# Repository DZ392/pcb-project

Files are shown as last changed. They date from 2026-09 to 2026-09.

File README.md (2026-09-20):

# pcb-project

🦋 Butterfly USB Hub Dongle

This is a small 4-port USB hub built into a butterfly-shaped PCB. Instead of using a cable like most USB hubs, it plugs directly into the side of a laptop.

I wanted to make something a more compact usb that can be used for anything I need, so I designed mine as a dongle and I wanted it to work with newer laptops that mostly use USB-C as well as older ones that still have USB-A.

The board has a male USB-C connector and a male USB-A connector for the laptop side. You only use one of them at a time depending on what port your laptop has.

I also wanted the PCB itself to be part of the design rather than just a rectangular board, so I shaped it like a butterfly and plan to add a UV-printed gradient design to it as a challenge. 

The PCB is 1.2 mm thick to work with the edge-mount USB connectors.

Why I Made It

I use devices with both USB-A and USB-C, and I thought it would be useful to have one small hub that could plug into either type of laptop without needing another adapter or cable. I also wanted to try designing my first PCB for practice. 

I started by following the Macondo USB hub tutorial to understand how a USB hub circuit works. From there, I changed the design, I added both USB-C and USB-A upstream connectors, changed it into a direct-plug dongle, designed the butterfly-shaped PCB, and added my own visual design.

This project has also helped to learn KiCad and understand how the schematic, PCB layout, footprints, connectors, and physical board shape all have to work together.

How to Use It

1. Plug either the USB-C or USB-A connector into your laptop. Only one should be connected at a time.
2. Plug USB-A devices into the three USB-A ports on the board.
3. A USB-C device can also be connected to the USB-C port on the hub.

* Hub IC: CoreChips SL2.1S
* USB standard: USB 2.0
* Upstream: 1 × male USB-C + 1 × male USB-A
* Downstream: 3 × female USB-A + 1 × female USB-C
* PCB: 2-layer, 1.2 mm thick
* Size: about 75 mm × 65 mm
* Board shape: custom butterfly
* External power: not required



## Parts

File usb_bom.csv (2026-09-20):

Reference | Quantity | Value/Function | Manufacturer | Manufacturer Part Number | LCSC Part Number
U2 | 1 | USB 2.0 hub controller | CoreChips | SL2.1s | C2684433
U3 | 1 | USB-C connector | G-Switch | GT-USB-7010ASV | C2988369
USB1 | 1 | USB-C female, 16-pin | Korean Hroparts Elec | TYPE-C-31-M-12 | C165948
USB7 | 1 | USB-A female, right-angle | SHOU HAN | AF 90 WJDG | C456018
USB10 | 1 | USB-A male | Korean Hroparts Elec | U-G-O4DD-W-1 | C98125
R1 R2 | 2 | 56 kΩ ±1%, 0402 | UNI-ROYAL | 0402WGF5602TCE | C25796
R6 | 1 | 5.1 kΩ ±1%, 0402 | UNI-ROYAL | 0402WGF5101TCE | C25905
C1 C3 C4 C6 C11 C18 C19 | 7 | 1 µF, 25 V, X5R, 0402 | Samsung Electro-Mechanics | CL05A105KA5NQNC | C52923
C2 C5 C7 | 3 | 100 nF, 50 V, X7R, 0402 | Samsung Electro-Mechanics | CL05B104KB54PNC | C307331

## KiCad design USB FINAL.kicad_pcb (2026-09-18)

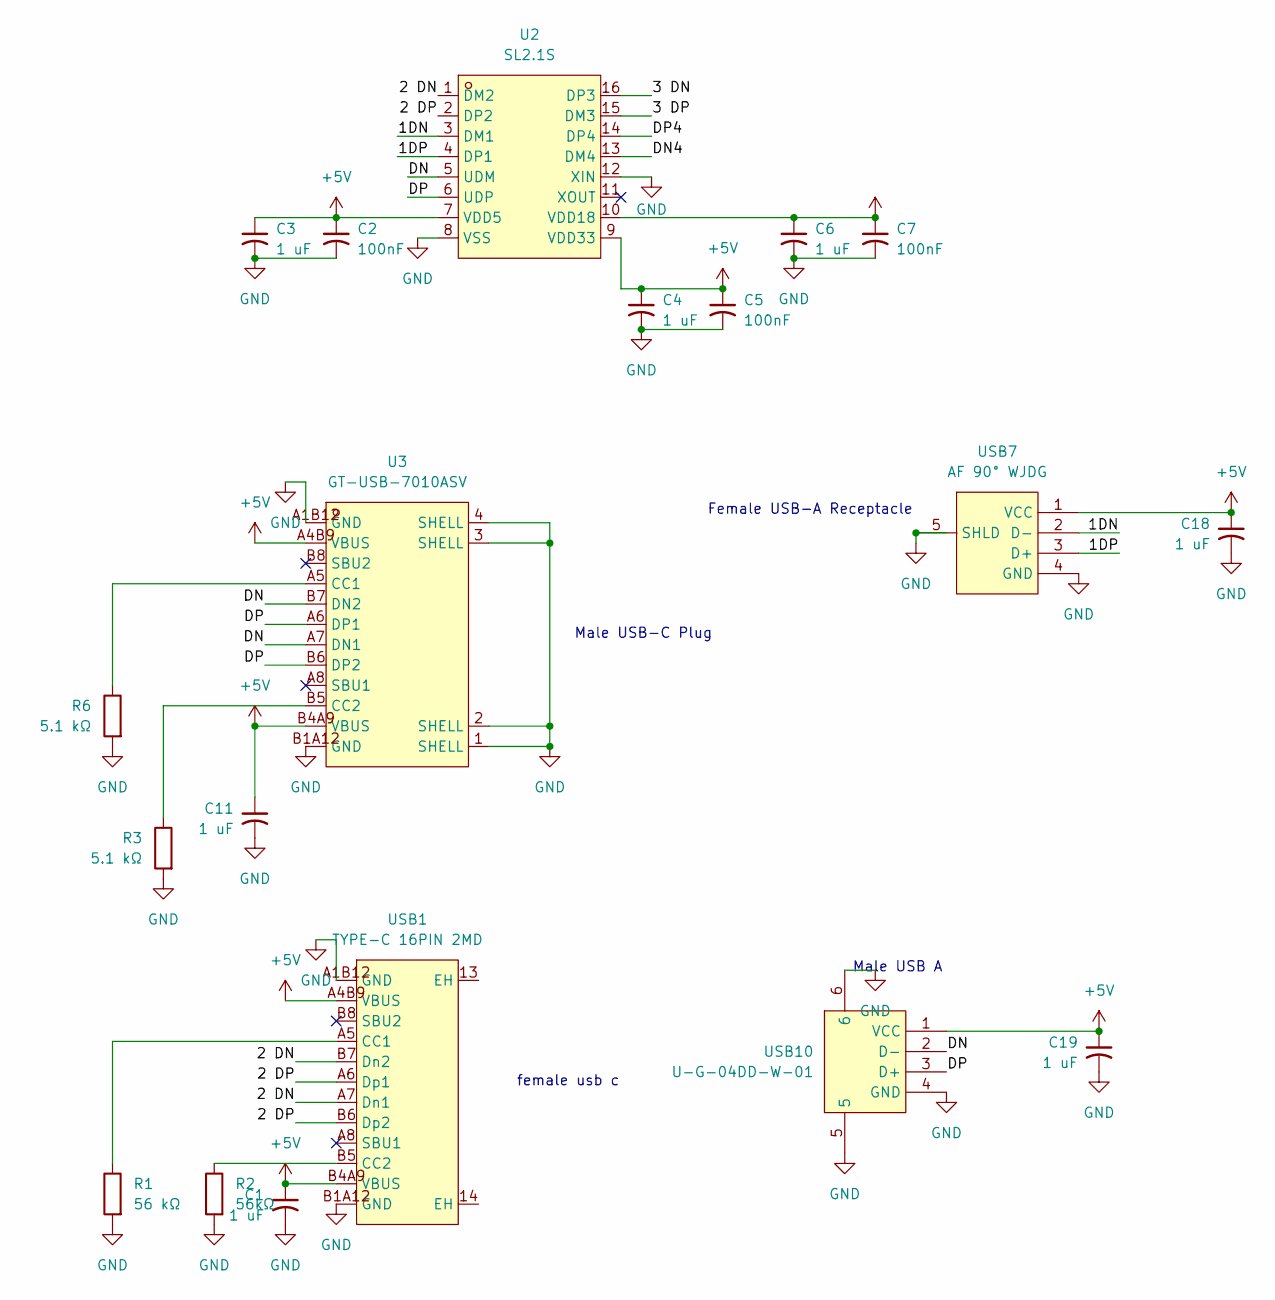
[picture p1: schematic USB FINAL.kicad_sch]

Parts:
C1, C3, C4, C6, C11, C18, C19: 1 uF; C_0805_2012Metric_Pad1.18x1.45mm_HandSolder
C2, C5, C7: 100nF; C_0805_2012Metric_Pad1.18x1.45mm_HandSolder
R1: 56 kΩ; R_0805_2012Metric_Pad1.20x1.40mm_HandSolder
R2: 56kΩ; R_0805_2012Metric_Pad1.20x1.40mm_HandSolder
R3, R6: 5.1 kΩ; R_0805_2012Metric_Pad1.20x1.40mm_HandSolder
U2: SL2.1S; SSOP-16_L4.6-W2.6-P0.53-LS4.0-BL; MPN SL2.1s; LCSC Part C2684433
U3: GT-USB-7010ASV; USB-C-SMD_G-SWITCH_GT-USB-7010ASV; MPN GT-USB-7010ASV; LCSC Part C2988369
USB1: TYPE-C 16PIN 2MD; USB-C-SMD_TYPE-C-16PIN-2MD-073; MPN TYPE-C 16PIN 2MD(073); LCSC Part C2765186
USB7: AF 90° WJDG; USB-A-TH_AF-WJDG; MPN AF 90° WJDG; LCSC Part C456018
USB10: U-G-04DD-W-01; USB-A-TH_U-G-04WD-W-01; MPN U-G-O4DD-W-1; LCSC Part C98125

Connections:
+5V: C1.1, C2.1, C3.1, C4.1, C5.1, C6.1, C7.1, C11.1, C18.1, C19.1, U2.7 (VDD5), U2.9 (VDD33), U2.10 (VDD18), U3.A4B9 (VBUS), U3.B4A9 (VBUS), USB1.A4B9 (VBUS), USB1.B4A9 (VBUS), USB7.1 (VCC), USB10.1 (VCC)
/1DN: U2.3 (DM1), USB7.2 (D-)
/1DP: U2.4 (DP1), USB7.3 (D+)
/2 DN: U2.1 (DM2), USB1.A7 (Dn1), USB1.B7 (Dn2)
/2 DP: U2.2 (DP2), USB1.A6 (Dp1), USB1.B6 (Dp2)
/3 DN: U2.16 (DP3)
/3 DP: U2.15 (DM3)
/DN: U2.5 (UDM), U3.A7 (DN1), U3.B7 (DN2), USB10.2 (D-)
/DN4: U2.13 (DM4)
/DP: U2.6 (UDP), U3.A6 (DP1), U3.B6 (DP2), USB10.3 (D+)
/DP4: U2.14 (DP4)
GND: C1.2, C2.2, C3.2, C4.2, C5.2, C6.2, C7.2, C11.2, C18.2, C19.2, R1.2, R2.2, R3.2, R6.2, U2.8 (VSS), U2.12 (XIN), U3.1 (SHELL), U3.2 (SHELL), U3.3 (SHELL), U3.4 (SHELL), U3.A1B12 (GND), U3.B1A12 (GND), USB1.A1B12 (GND), USB1.B1A12 (GND), USB7.4 (GND), USB7.5 (SHLD), USB10.4 (GND), USB10.5, USB10.6
unnamed: R6.1, U3.A5 (CC1)
unnamed: R3.1, U3.B5 (CC2)
unnamed: R1.1, USB1.A5 (CC1)
unnamed: R2.1, USB1.B5 (CC2)

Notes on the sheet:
Male USB-C Plug
female usb c
Female USB-A Receptacle
Male USB A

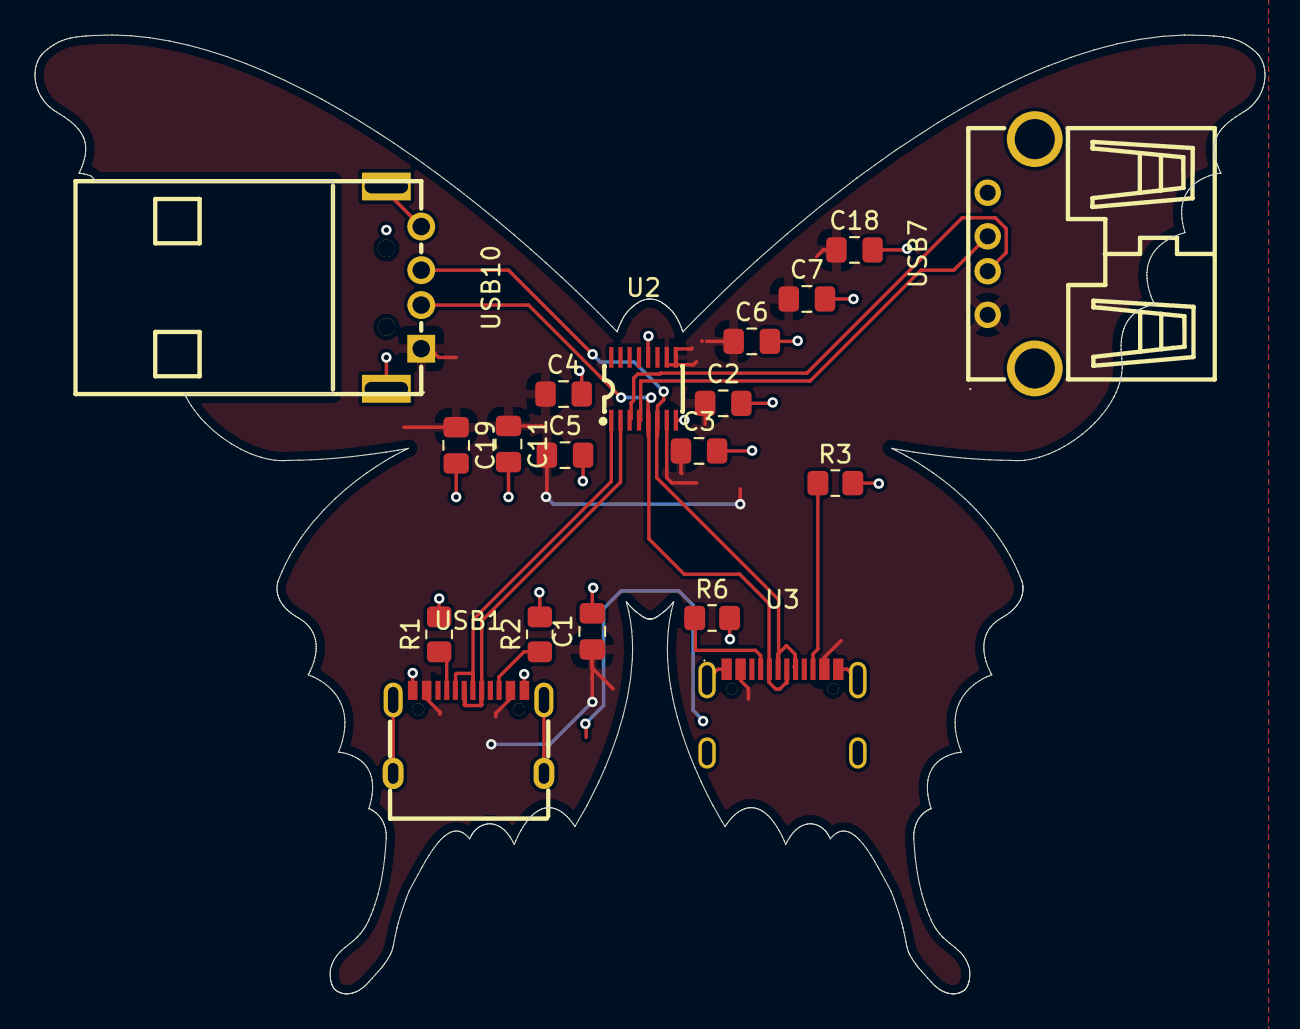
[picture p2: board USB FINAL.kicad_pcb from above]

Board: 2 copper layers, 70.5 x 55.0 mm, 19 parts (0 on the bottom side), 12 nets.
